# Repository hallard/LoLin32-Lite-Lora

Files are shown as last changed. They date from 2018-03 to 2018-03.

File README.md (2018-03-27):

# ESP32 LoLin32 Lite Lora Shield for RFM95 or RN2483

This shield is used to hold LoRa modules such as HopeRF [RFM95][4] or Mictrochip [RN2483][7] with WeMos ESP32 [LoLin32-Lite][22] boards it has the followong features:
- I2C Pullups placement
- Classic I2C connector with SCL/SDA and 3V3/GND reversable pin by solder pad
- Groove I2C connector
- Footprint for RFM95/96/98 or RN2483/RN2903 Lora module
- Footprint for choosing single Wire, SMA or u-FL Antenna type 
- 1 x WS2812B Type LED for visual indication
- 1 x Push Button
- Added footprint for Microchip 24AA02E64 64 bits serial number (DEVEUI)

Take care that WeMos has different Lolin32 boards, you need the [Lite][22] model. They Provide WeMos [Lolin32][20], [Lolin32 Pro][21] or this one [Lolin32 Lite][22]

You can also check the shield for the [Lolin32 (not Lite)][9] classic version. 

# Detailed Description

Look at the schematics for more informations.

SPI connexion is classic (MOSI/MISO/CLK), 

Other pins that may need be adapted into code (for example if you use TTN network gateway code) according to the following pinout

```
Lolin32-Lite   RFM9x Module
  IO5   <-------> SEL 
  IO19  <-------> MISO
  IO23  <-------> MOSI
  IO18  <-------> CLK
  IO27  <-------> DIO0
  IO26  <-------> DIO1
  IO4   <-------> DIO2
  IO25  <-------> RST
  IO35  <-------> DIO5

Lolin32-Lite   RN2xx3 Module
  IO4   <-------> RESET
  IO25  <-------> RX
  IO35  <-------> TX

Lolin32-Lite   Shield Feature
  IO12  <-------> I2C SCL
  IO14  <-------> I2C SDA
  IO13  <-------> WS2812 LEDS
  IO15  <-------> Push Button

Lolin32-Lite Free I/O
  IO0  -> Also used for Flash
  IO2 
  IO16 
  IO17
  IO22 -> On Board LoLin32-Lite LED
  IO32
  IO33 
  IO34 
```

**Do not forget to join (solder) the correct LoRa antenna trace** depending on module you place (RFM95 or RN2483), see picture below.

Antenna Solder Pad

And as classic advice, **connect the LoRa antenna before powering** the board to avoid any damage to LoRa module

# Schematic  

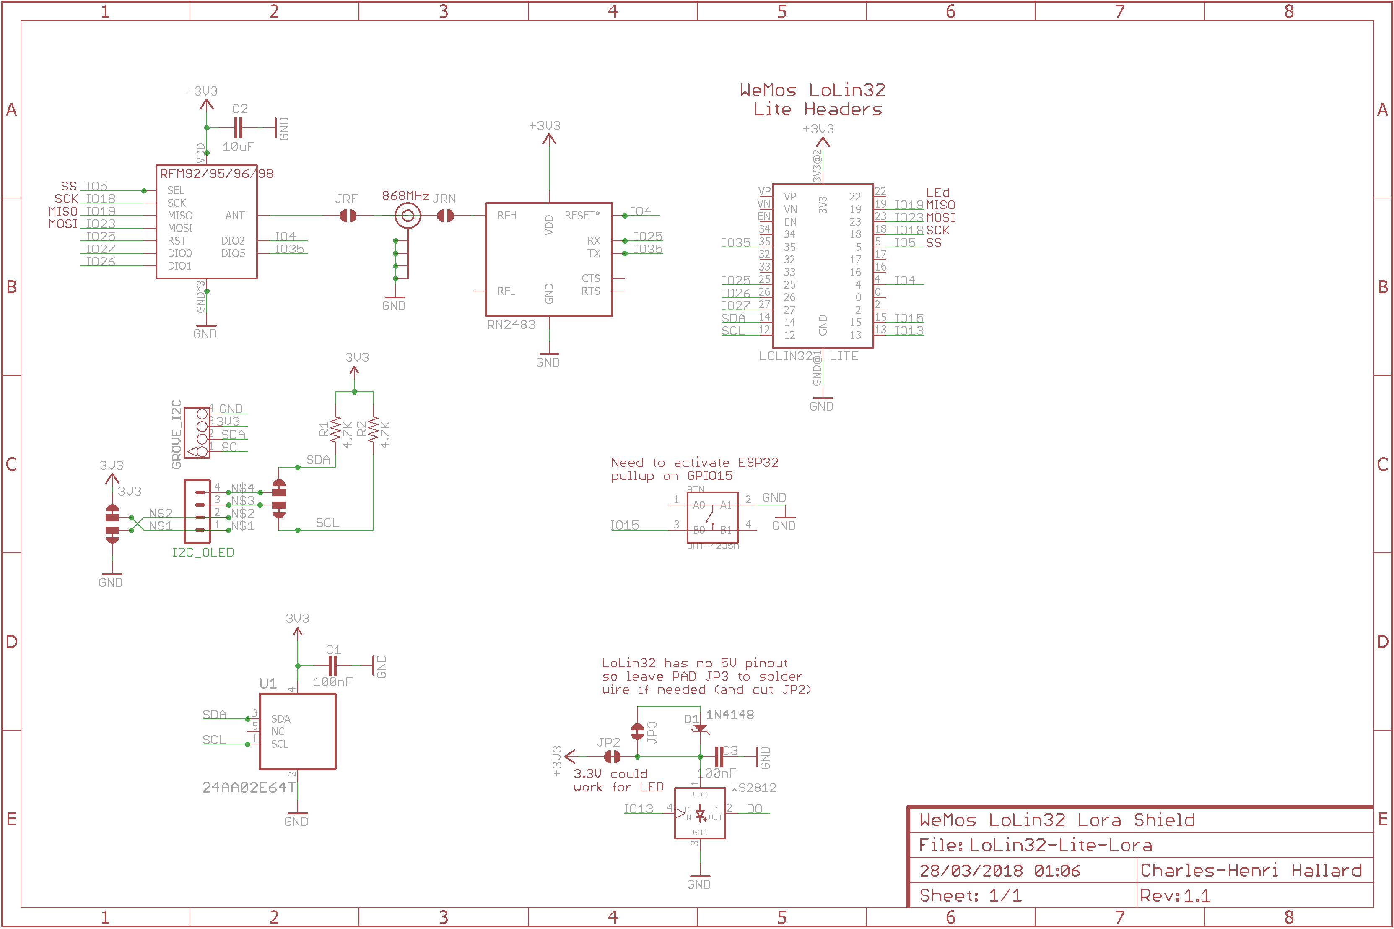
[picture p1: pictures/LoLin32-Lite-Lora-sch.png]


# Firmware  

There is no firmware available, but you can have a large demo of features and a full working LoRa node (with RFM95) with this excellent [ESP32-Paxcounter](https://github.com/cyberman54/ESP32-Paxcounter/) software, it's a must see.

# Boards  

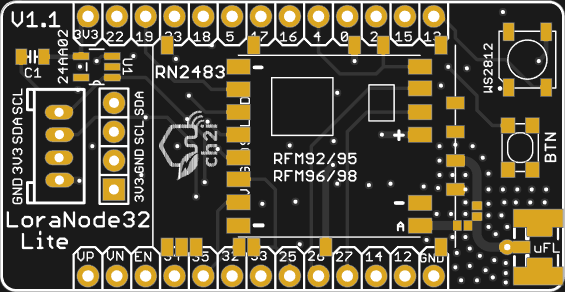
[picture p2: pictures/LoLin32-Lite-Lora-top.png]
Top
&nbsp;
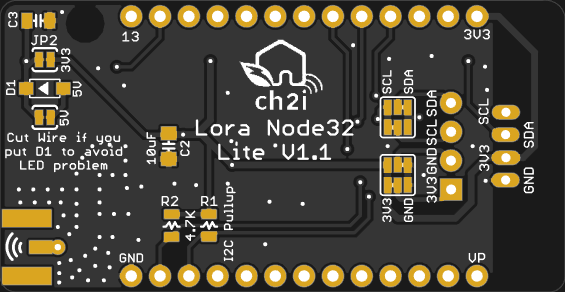
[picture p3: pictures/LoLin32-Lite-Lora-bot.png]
Bottom


You can order the PCB of this board at [PCBs.io][8]. PCBs.io give me some reward when you order my designed boards from their site. This is pretty good, because I can use these rewards to create and design new boards and order them for free, so if you don't care about PCB manufacturer please use PCBs.io.

# Assembled boards (TBD)

Not assembled yet but you can see approx what it looks like with the [Lolin32 (not Lite)][9] version. 

## With RFM95

LoraNode32 with RFM95

## With RN2483

LoraNode32 with RN2483

# License

   

This work is licensed under a [Creative Commons Attribution-NonCommercial 4.0 International License](http://creativecommons.org/licenses/by-nc/4.0/)    
If you want to do commercial stuff with this project, please contact [CH2i company](https://ch2i.eu/en#support) so we can organize an simple agreement.

# Misc

See news and other projects on my [blog][2] 
 
[2]: https://hallard.me
[3]: https://PCBs.io/share/zO3Ye
[4]: http://www.hoperf.com/rf_transceiver/lora/
[5]: https://github.com/hallard/ESP-1ch-Gateway/
[6]: https://github.com/matthijskooijman/arduino-lmic/pull/34
[7]: https://www.microchip.com/wwwproducts/en/RN2483
[8]: https://PCBs.io/share/4Qvx1
[9]: https://github.com/hallard/LoLin32-Lora

[10]: http://www.banggood.com/WeMos-LOLIN32-V1_0_0-WiFi-Bluetooth-Board-Based-ESP-32-4MB-FLASH-p-1164252.html

[20]: https://wiki.wemos.cc/products:lolin32:lolin32
[21]: https://wiki.wemos.cc/products:lolin32:lolin32_pro
[22]: https://wiki.wemos.cc/products:lolin32:lolin32_lite

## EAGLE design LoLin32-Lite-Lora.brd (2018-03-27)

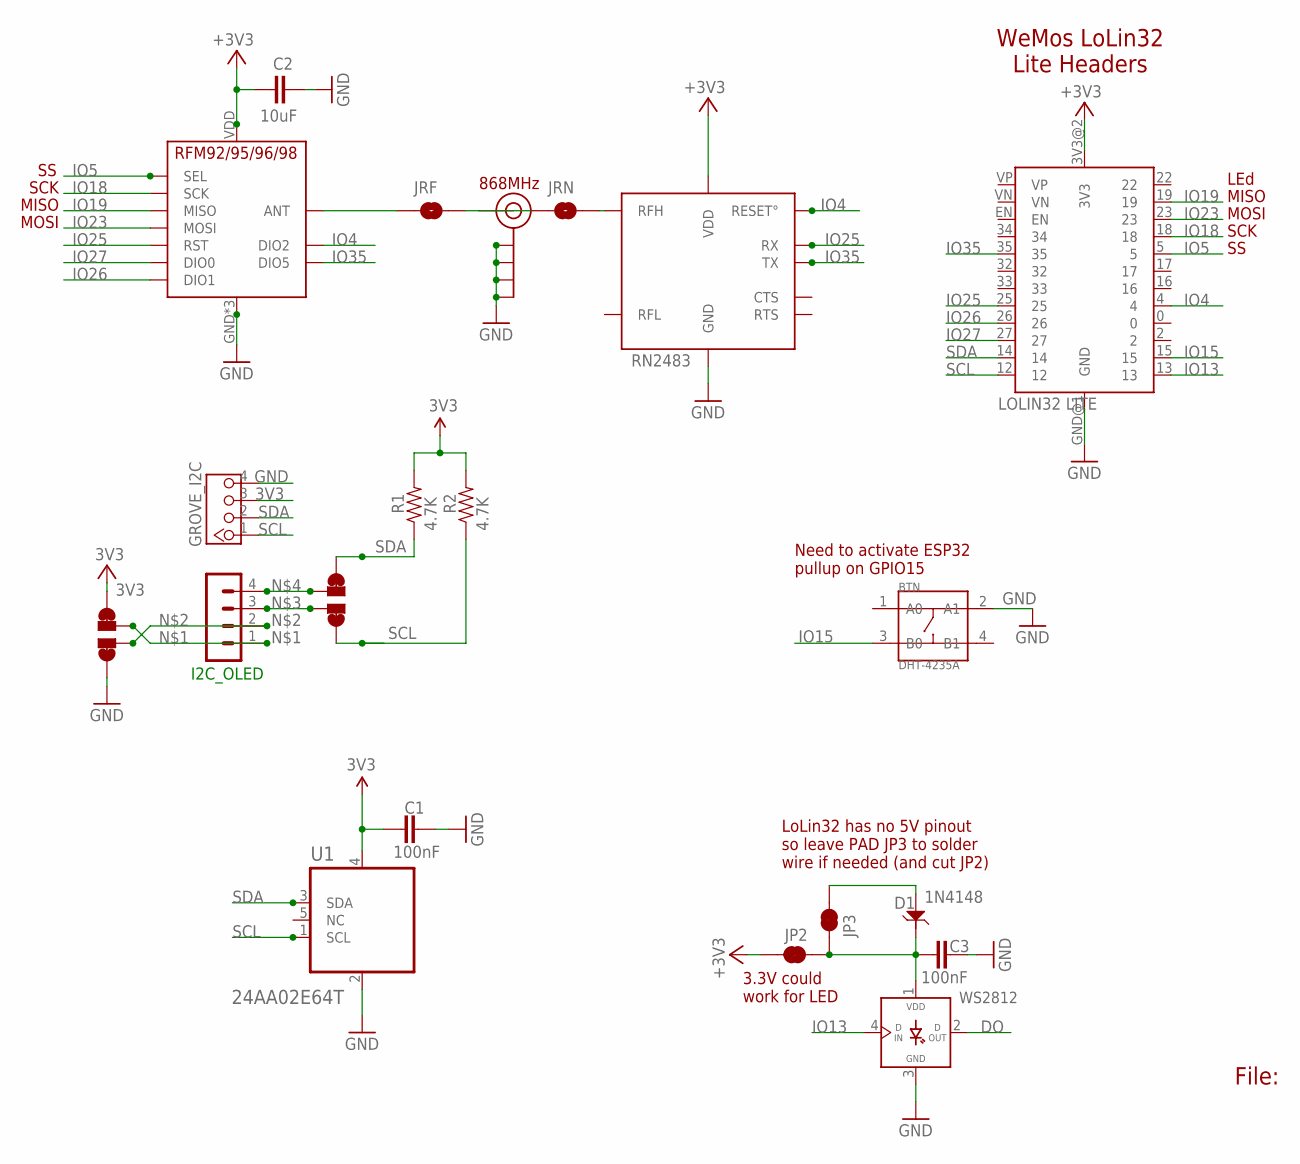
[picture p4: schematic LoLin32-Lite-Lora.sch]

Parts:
BTN: DHT-4235A; SW4-SMD-4.2X3.2X2.5MM
C1, C3: 100nF; 0805-CAP
C2: 10uF; 0805-CAP-LARGEPADS
D1: 1N4148; SOD123-2.7X1.6
GROVE_I2C: 4P-2.0; HW4-2.0
I2C_OLED: CON_HEADER_1X04'NO_LOCK'; 1X04_NO_LOCK
J$2: ANTENNATINY; SMA_UFL_PAD_TINY
JP2: RXLED; PAD-JUMPER-2-NC_BY_TRACE_YES_SILK
JP3: JUMPER-PAD-2-NC_BY_TRACE; PAD-JUMPER-2-NC_BY_TRACE_YES_SILK
JRF: JUMPER-PAD-2-NO; PAD-JUMPER-2-NO_NO_SILK
JRN: JUMPER-PAD-2-NO; PAD-JUMPER-2-NO_NO_SILK
R1, R2: 4.7K; 0805-RES
U1: 24AA02E64T; SOT95P270X145-5N
U$1: LOLIN32 LITE; LOLIN32_LITE
U$2, U$3: PAD-JUMPER-SWAPSWAP; PAD-JUMPER-SWAP
U$5: RFM95
U$7: RN2483; RN2483_NOGPIO_868
WS2812: WS2812B

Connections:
3V3: C1.1, C2.2, GROVE_I2C.3, JP2.2, R1.2, R2.2, U1.4 (VCC), U$1.3V3@2 (3V3), U$2.4, U$2.44 (4), U$5.VDD (VCC), U$7.VDD, U$7.VDD2 (VDD)
5V: D1.1, JP3.2
DO: WS2812.2 (DOUT)
GND: BTN.2 (A1), C1.2, C2.1, C3.2, GROVE_I2C.4, J$2.GND1 (GND), J$2.GND2 (GND), J$2.GND3 (GND), J$2.GND4 (GND), U1.2 (VSS), U$1.GND@1 (GND), U$2.1, U$2.11 (1), U$5.GND, U$5.GND1 (GND), U$5.GND2 (GND), U$7.GND, U$7.GND3 (GND), U$7.GND4 (GND), U$7.GND7 (GND), U$7.GND9 (GND), U$7.GND11 (GND), U$7.GND12 (GND), WS2812.3 (GND)
IO4: U$1.4, U$5.DIO2, U$7.RESET°
IO5: U$1.5, U$5.NSS (SEL)
IO13: U$1.13, WS2812.4 (DIN)
IO15: BTN.3 (B0), U$1.15
IO18: U$1.18, U$5.SCK
IO19: U$1.19, U$5.MISO
IO23: U$1.23, U$5.MOSI
IO25: U$1.25, U$5.RST, U$7.UART_RX (RX)
IO26: U$1.26, U$5.DIO1
IO27: U$1.27, U$5.DIO0
IO35: U$1.35, U$5.DIO5, U$7.UART_TX (TX)
unnamed: I2C_OLED.1, U$2.3
unnamed: I2C_OLED.2, U$2.2
unnamed: I2C_OLED.3, U$3.2
unnamed: I2C_OLED.4, U$3.3
unnamed: JRN.2, U$7.RFH
unnamed: JRF.1, U$5.ANT
unnamed: J$2.ANT1 (SIGNAL), J$2.ANT2 (SIGNAL), J$2.ANT3 (SIGNAL), JRF.2, JRN.1
SCL: GROVE_I2C.1, R2.1, U1.1 (SCL), U$1.12, U$3.1, U$3.11 (1)
SDA: GROVE_I2C.2, R1.1, U1.3 (SDA), U$1.14, U$3.4, U$3.44 (4)
VLED: C3.1, D1.2, JP2.1, JP3.1, WS2812.1 (VDD)

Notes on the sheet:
File:
WeMos LoLin32 Lite Headers
868MHz
MOSI
MISO
SCK
Need to activate ESP32 pullup on GPIO15
LEd
LoLin32 has no 5V pinout so leave PAD JP3 to solder wire if needed (and cut JP2)
3.3V could work for LED

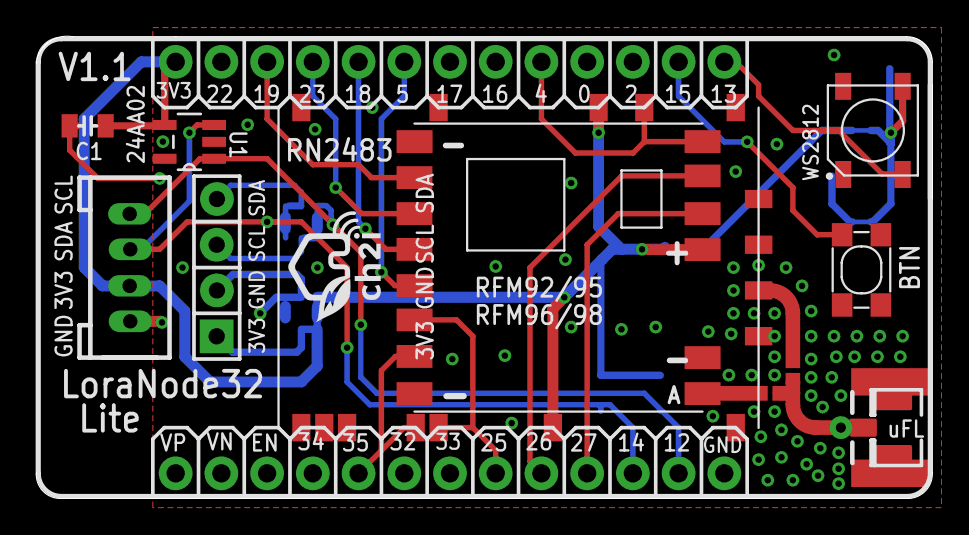
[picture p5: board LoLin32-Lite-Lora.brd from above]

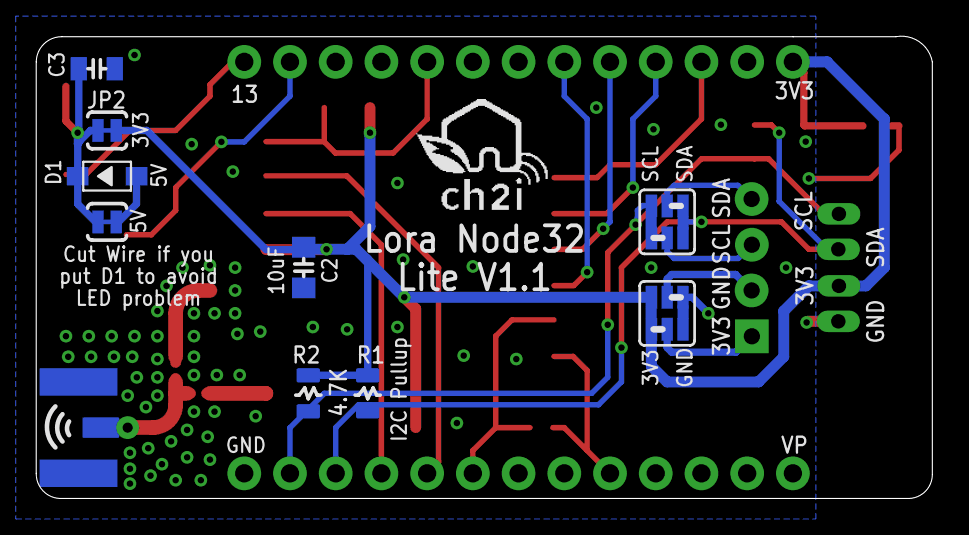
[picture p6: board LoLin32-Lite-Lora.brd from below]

Board: 2 copper layers, 49.8 x 25.7 mm, 23 parts (10 on the bottom side), 24 nets.

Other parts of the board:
U$4: LOGO_CH2I_75MM
U$6: LOGO_C2I_015

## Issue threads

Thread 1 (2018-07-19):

LITE retired

urs8000, 2018-07-19:
hi Charles
your mentioned board is also retired.  https://wiki.wemos.cc/products:lolin32:lolin32_lite

they now thave the D32 https://wiki.wemos.cc/products:d32:d32
is your shield compatible with that one?

thanks, urs

urs8000, 2018-07-19:
I checked pin numbering.   It's NOT compatible with your shield

do you create a new one for the hopefully longer available version D32?

hallard, 2018-07-19:
I was not aware of a new board, with once again a new pinout.
I'm sorry, but I have no time to follow each change on their side
I done Lolin32 shield, Lolin32 lite shield and now a new board

I suggest you order old board on banggood such as
lite https://www.banggood.com/Wemos-LOLIN32-Lite-V1_0_0-Wifi-Bluetooth-Board-Based-ESP-32-Rev1-MicroPython-4MB-FLASH-p-1237861.html
original
https://www.banggood.com/WeMos-LOLIN32-V1_0_0-WiFi-Bluetooth-Board-Based-ESP-32-4MB-FLASH-p-1164252.html

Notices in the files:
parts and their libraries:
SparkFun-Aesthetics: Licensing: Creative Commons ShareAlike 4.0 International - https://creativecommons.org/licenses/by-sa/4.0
